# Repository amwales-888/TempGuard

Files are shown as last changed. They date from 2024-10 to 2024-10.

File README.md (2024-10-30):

# TempGuard
PID Temperature Controller dsPIC33EV64GM004 Hardware/Firmware 

Initial requirements were to control the temperature of an enclosed system, holding it as close as possible to a set temperature during operation. Venting air out of the enclosure using a FAN would quickly bring the temperature inside the enclosure to match the outside temperature which was unacceptable. Using an MCU we can monitor the temperature and vent air using a fan at a controlled rate. PID algorythms are commonly used in such systems - ['A proportional–integral–derivative controller (PID controller or three-term controller) is a control loop mechanism employing feedback that is widely used in industrial control systems and a variety of other applications requiring continuously modulated control.'](https://en.wikipedia.org/wiki/Proportional%E2%80%93integral%E2%80%93derivative_controller)

[dsPIC33EV64GM004](https://www.microchip.com/en-us/product/dsPIC33EV64GM004) MCU using 20MHz oscllator, configured with 140MHz FOSC ( 70 MIPS ). This device was selected based on pincount, cost and flexibility of its peripherals. It is presented in a surface mount 44pin quad flat pack that is easily hand solderable, along with a respectable 64k of flash and 8k RAM.

- 4 Input Capture devices for interfacing with temp sensors supporting [DHT11](docs/DHT11-Technical-Data-Sheet-Translated-Version-1143054.pdf) and [DHT22](docs/DHT22.pdf) protocols
- 3 2-Channel PWM devices running at 25KHz for controlling [4pin PWN fans](docs/4_Wire_PWM_Spec.pdf). Support for 3pin and 2pin fans using PWM on power pin if required
- 1 UART for communication, loggin with a host, configured at 9600 8N1
- 11 GPIOs connected to [2004 LCD (HD44780)](docs/HD44780.pdf) driven using 8bit Data, RS, RW and Enable, reading busy-flag to ensure maximum output throughput
- 12 GPIOs
  - 2 dedicated to rotary encoder ( GPIO4, GPIO5 )
  - 1 dedicated to a button ( GPIO3 )
  - 3 Inputs used to read TACH from 4PIN and 3PIN fans to calculate RPM 
  - 3 Output to FETs used as low-side switches controlling the FAN 12V power in the case of 3pin and 2pin fans and for power off control of 4pin fans
- 3 spare GPIO0, GPIO1, GPIO2 which can be used for notification of ALARM conditions, ie. FAN not spinning or Sensor not returning data.
- 3 Timers
  - TMR1 used as system timer used to monitor 10ms tick for scheduling
  - TMR3 used by PWM hardware
  - TMR4 used as high frequency timer with 7.3us tick

The system runs with a simple co-operative multitasking round-robin scheduler with a 10ms tick rate and ability to use a second high resultion timer with a 7us period. Tasks can be scheduled with or without a period, added and removed during operation. All tasks are non-blocking.

User interaction is through an LCD display current value from the attached temp sensors and fans. A rotary encoder and button can be used to navigate menus and change settings.

The LCD is updated from an in memory buffer at >120 times a second.

Ouput is also sent via UART over USB for logging purposes.

The firmware was developed usng the Microchip tools, [MPLABX](https://www.microchip.com/en-us/tools-resources/develop/mplab-x-ide) (v6.10) using [XC16](https://www.microchip.com/en-us/tools-resources/develop/mplab-xc-compilers/xc16) (v2.10) compiler and [MCC](https://www.microchip.com/en-us/tools-resources/configure/mplab-code-configurator) (v5) used to generate system, clock and initialisation code for hardware peripherals.

The firmware is written to the MCU in-circuit using a Microchip [Pickit5](https://www.microchip.com/en-us/development-tool/PG164150). Using the Pickit5 it is also possible to do source level debugging of the MCU while in-circuit.

For test and verification the first version of the device was coded on a dsPIC33EV64GM002 28pin DIP version of the device and soldered onto stripboard, the results for a 40minute session were logged, once the enclosure reached the required set temperature their was little to no deviation seen over the 40minutes.

## Hardware/Enclosure

<table>
  <tr>
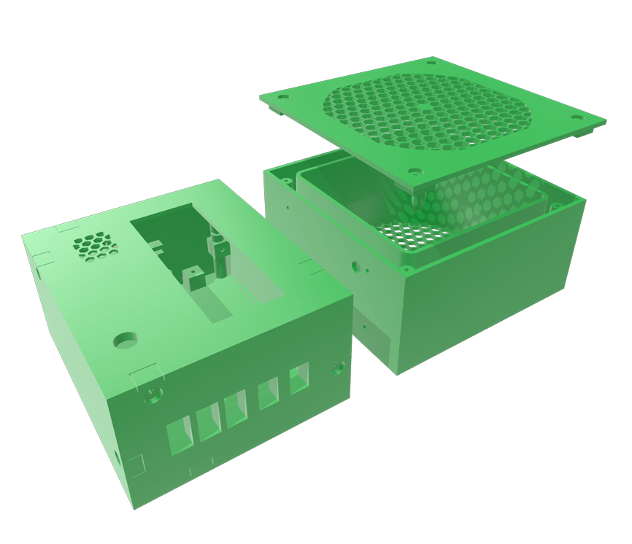
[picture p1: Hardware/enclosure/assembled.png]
    <td colspan="2"> </td>
  </tr>
  <tr>
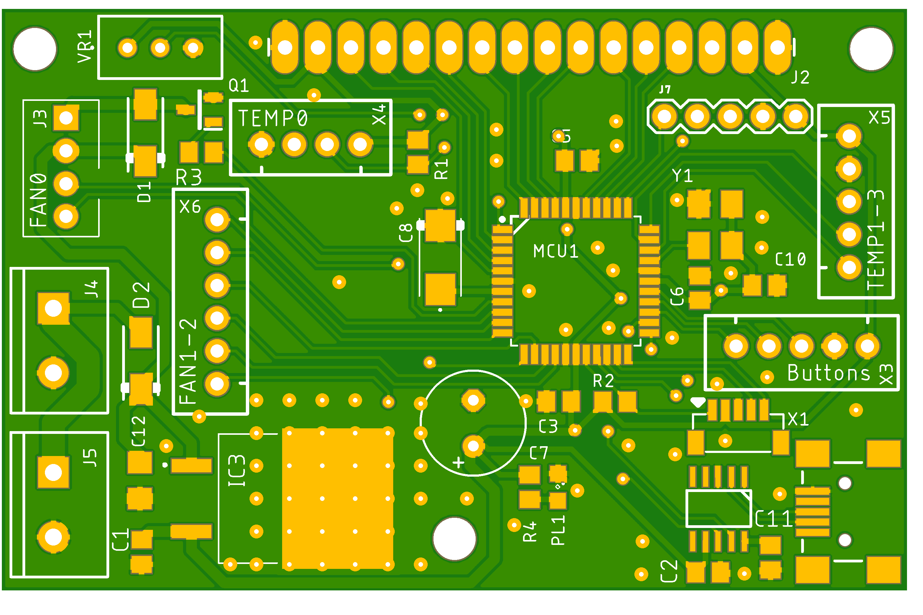
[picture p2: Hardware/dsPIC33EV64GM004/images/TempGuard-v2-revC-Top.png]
    <td> </td>
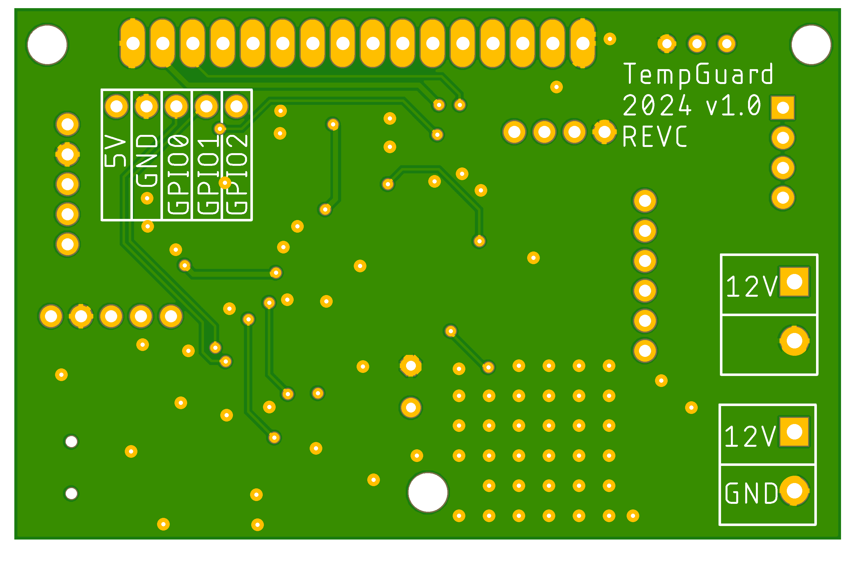
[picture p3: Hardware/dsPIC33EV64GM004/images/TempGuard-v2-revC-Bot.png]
    <td> </td>
  </tr>
  <tr>
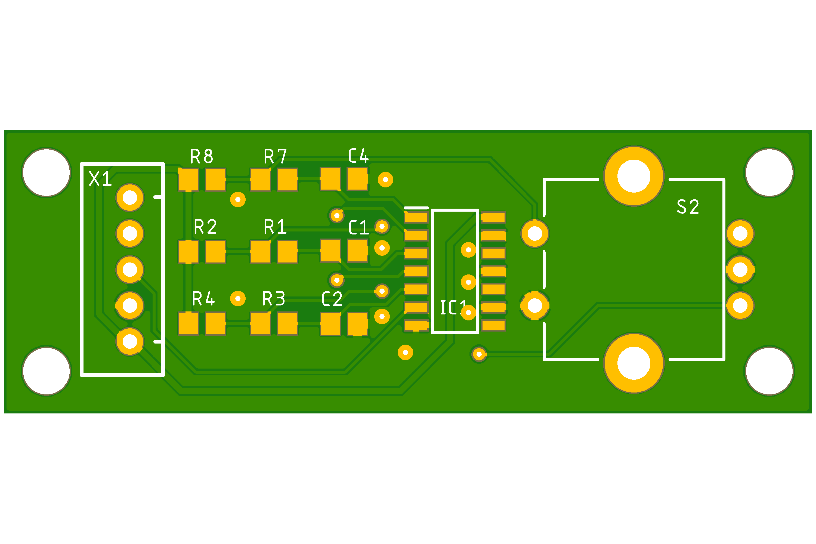
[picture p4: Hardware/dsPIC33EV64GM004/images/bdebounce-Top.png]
    <td> </td>
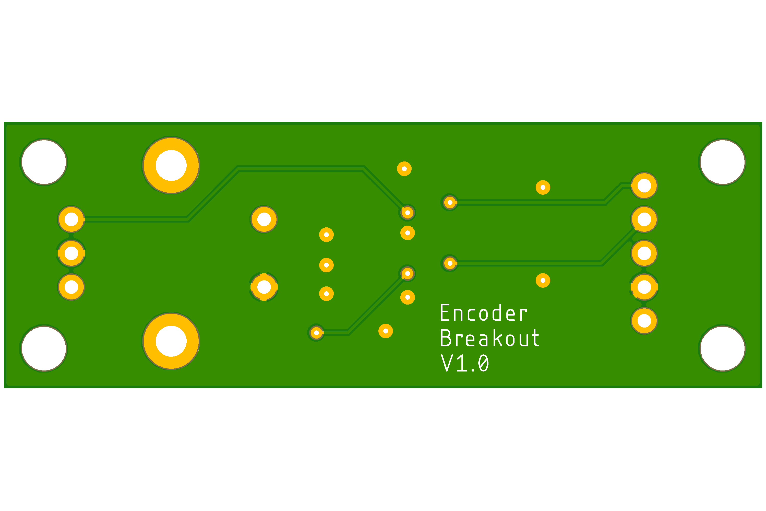
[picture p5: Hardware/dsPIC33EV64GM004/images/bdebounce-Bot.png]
    <td> </td>
  </tr>
  <tr>
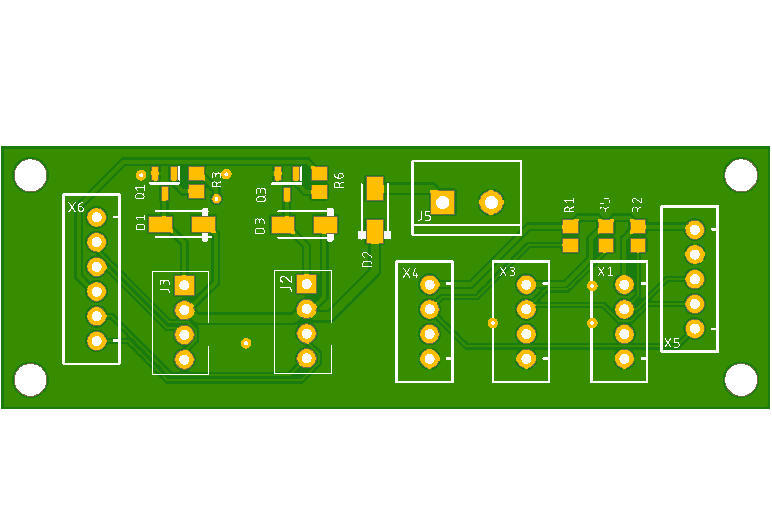
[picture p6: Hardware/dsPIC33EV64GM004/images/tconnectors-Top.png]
    <td> </td>
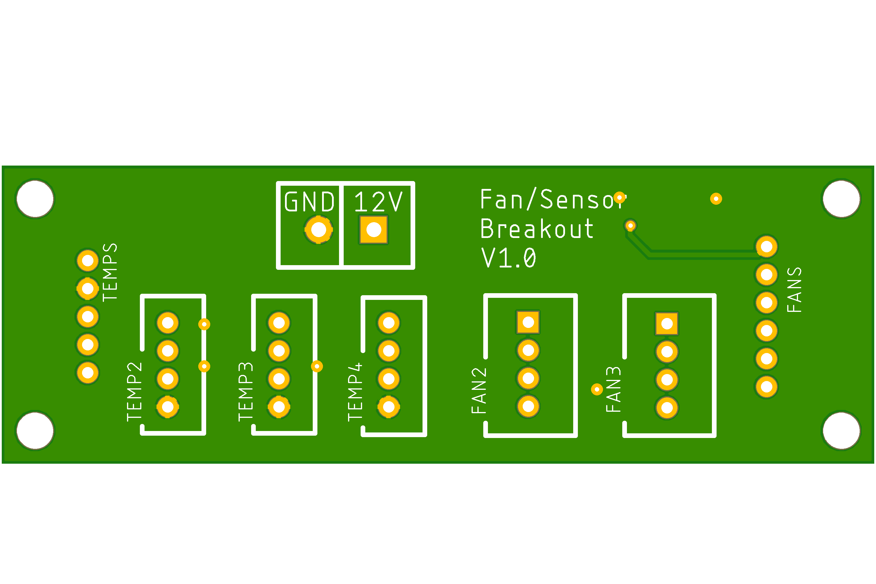
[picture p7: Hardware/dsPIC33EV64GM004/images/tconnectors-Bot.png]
    <td> </td>
  </tr>
</table>

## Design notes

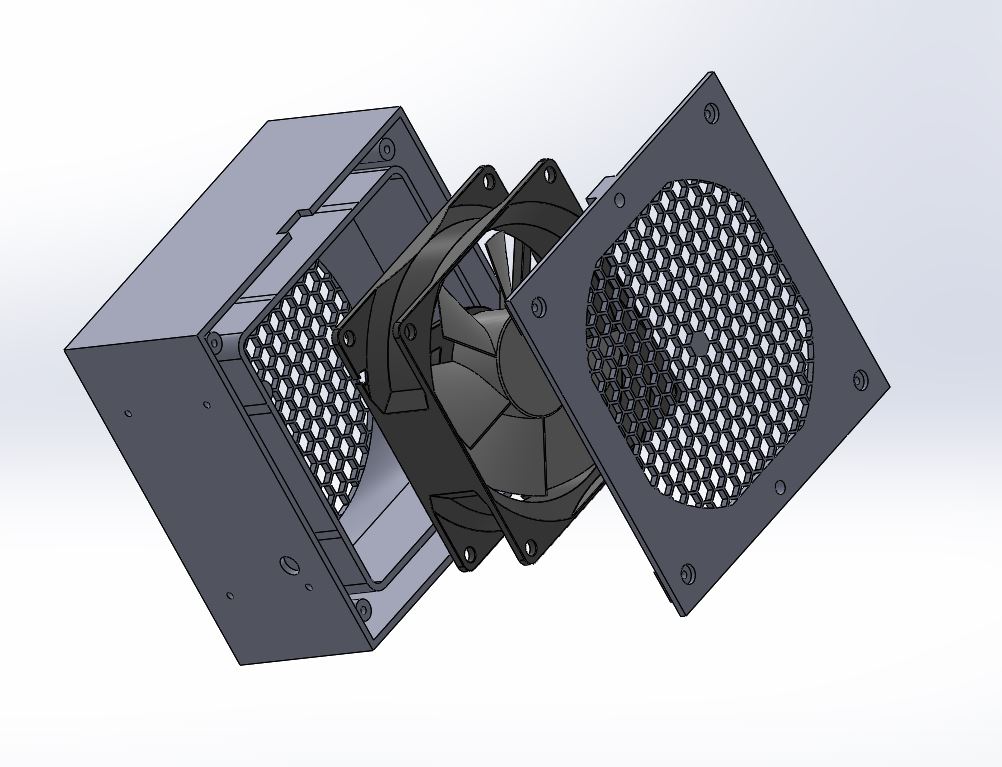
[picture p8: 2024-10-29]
Hardware/enclosure/fan.jpg

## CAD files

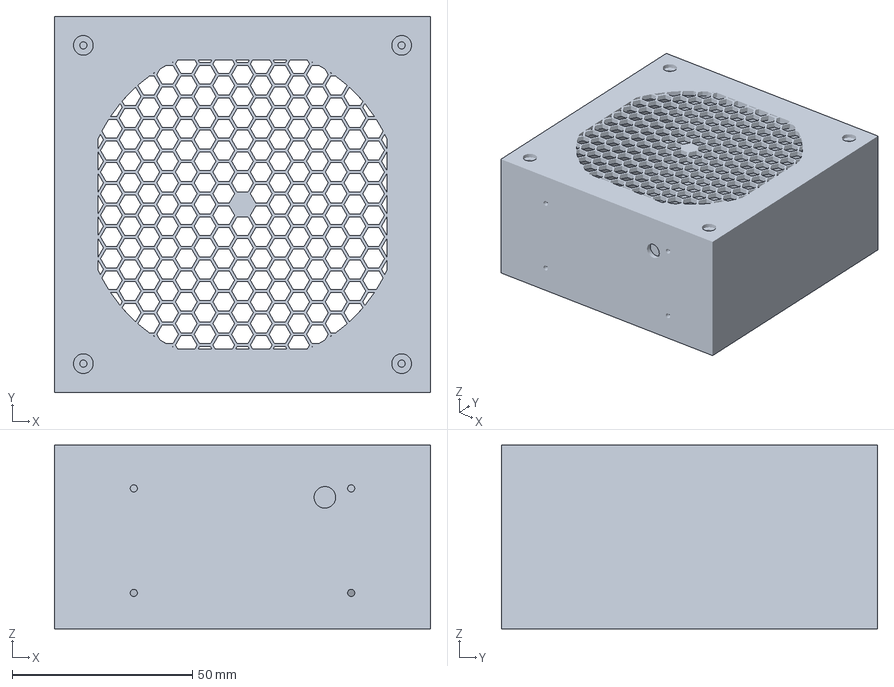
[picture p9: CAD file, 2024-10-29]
Hardware/enclosure/fanenclosure-v2.3MF
104.3 x 104.3 x 51.0 mm

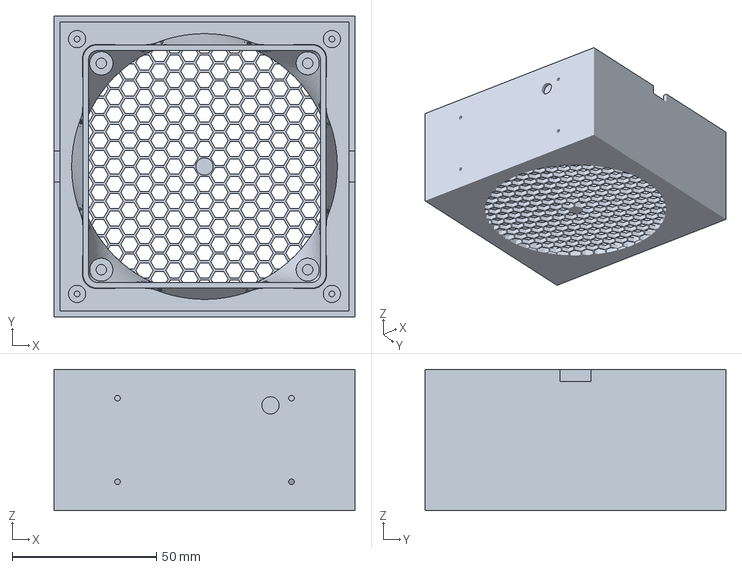
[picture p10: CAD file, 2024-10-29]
Hardware/enclosure/Fan1.3MF
104.3 x 104.3 x 49.0 mm

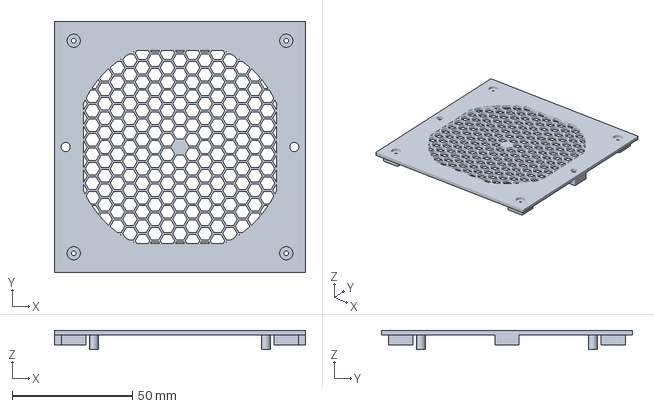
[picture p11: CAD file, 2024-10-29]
Hardware/enclosure/Fan2.3MF
104.3 x 104.3 x 8.00 mm

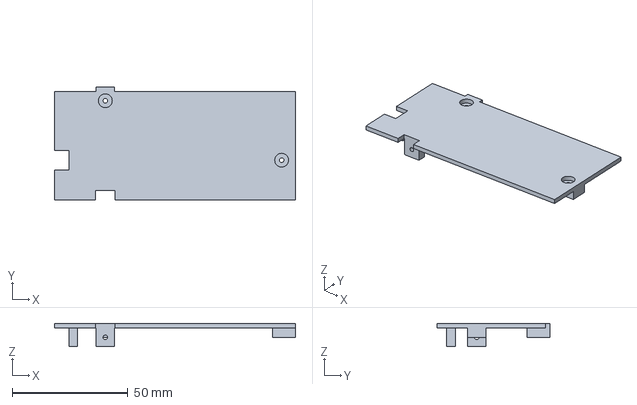
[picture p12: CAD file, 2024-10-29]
Hardware/enclosure/Part5.3MF
104.3 x 49.0 x 10.0 mm

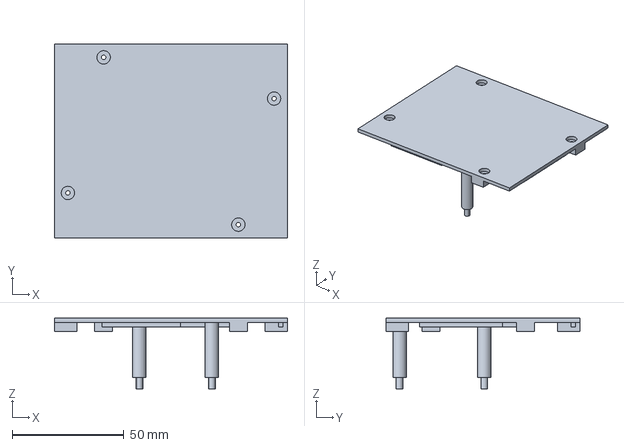
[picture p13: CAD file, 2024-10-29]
Hardware/enclosure/Part6.3MF
104.3 x 86.9 x 31.7 mm

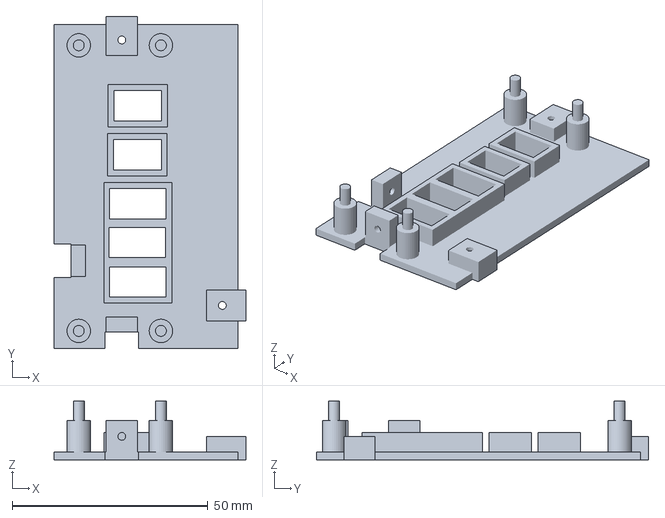
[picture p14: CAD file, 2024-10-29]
Hardware/enclosure/Part1.3MF
49.0 x 84.9 x 15.0 mm

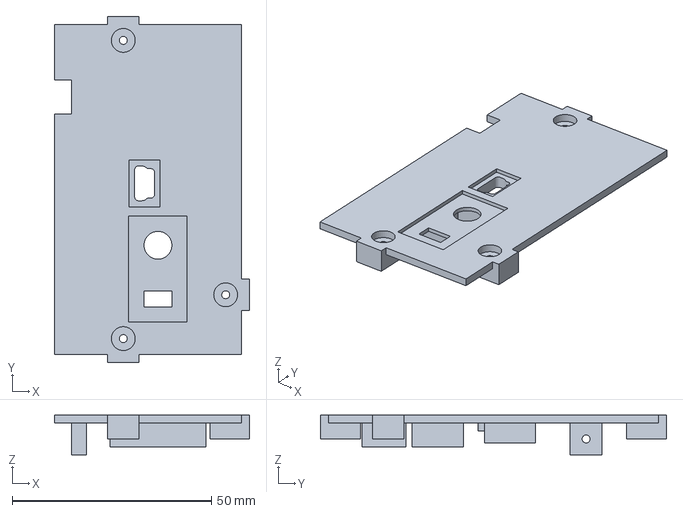
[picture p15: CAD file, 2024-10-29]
Hardware/enclosure/Part4.3MF
49.0 x 86.9 x 10.0 mm

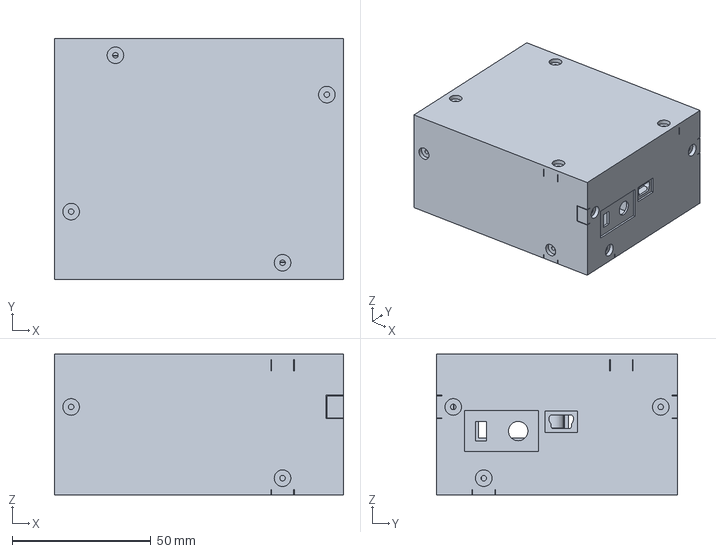
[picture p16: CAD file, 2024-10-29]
Hardware/enclosure/tempguard-v2.3MF
104.3 x 86.9 x 50.8 mm

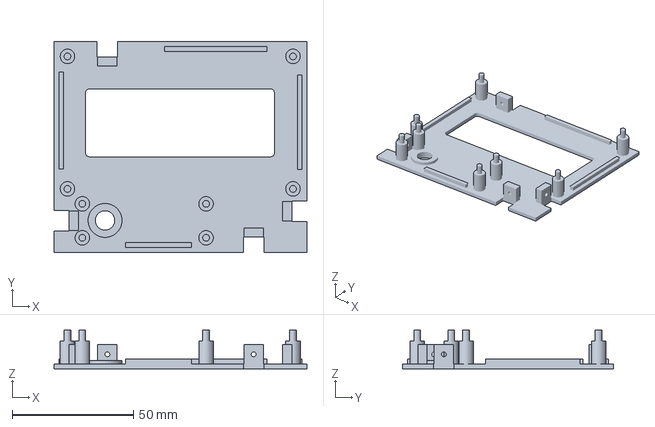
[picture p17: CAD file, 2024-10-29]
Hardware/enclosure/Part2.3MF
104.3 x 86.9 x 16.0 mm

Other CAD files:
Hardware/enclosure/Part3.3MF

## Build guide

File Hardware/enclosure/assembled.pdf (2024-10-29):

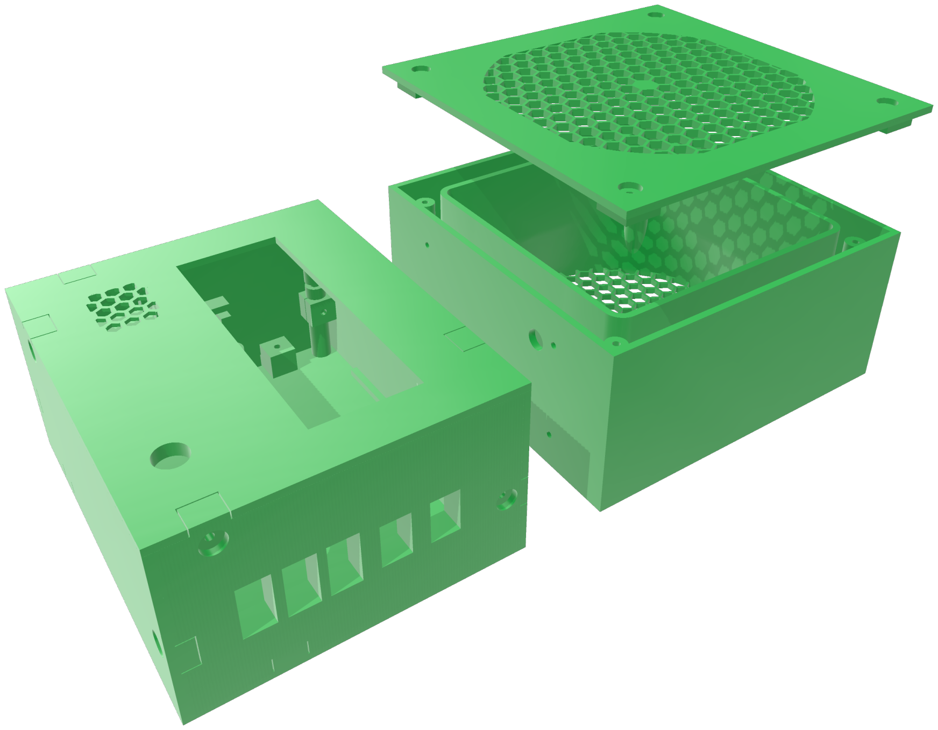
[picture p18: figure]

fanenclosure-v2

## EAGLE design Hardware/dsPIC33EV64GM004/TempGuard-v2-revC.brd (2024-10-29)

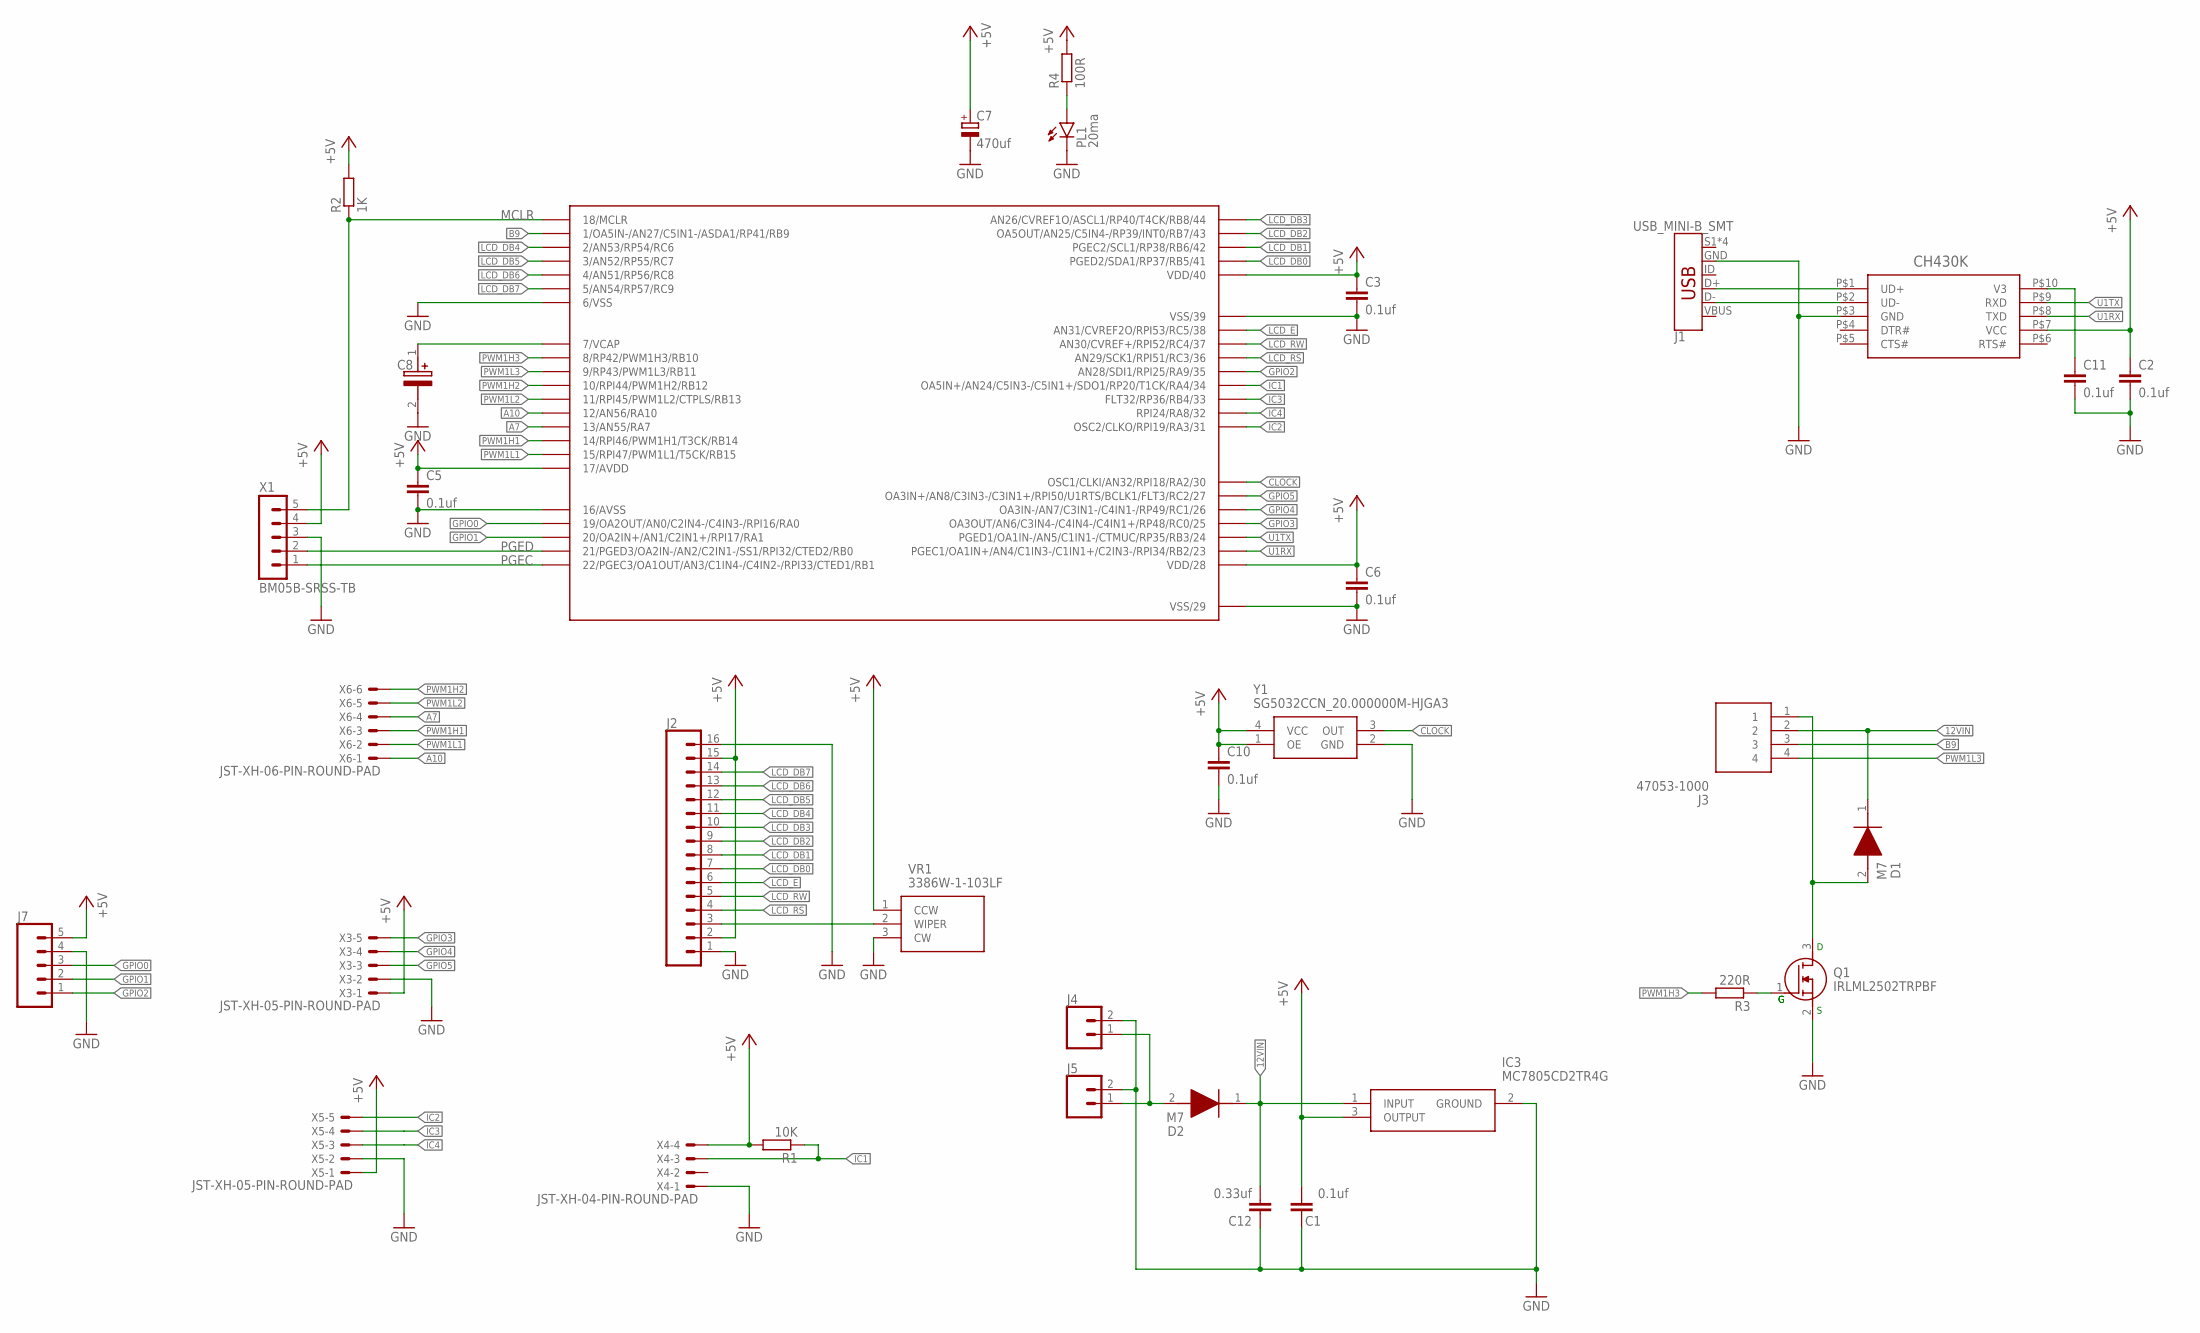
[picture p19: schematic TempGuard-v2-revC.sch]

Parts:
C1, C2, C3, C5, C6, C10, C11: 0.1uf; C0805
C7: 470uf; E3,5-8
C8: T491C106K016ATAUTO; T491C
C12: 0.33uf; C1206
D1, D2: M7; DIOM5327X240N
IC3: MC7805CD2TR4G
J1: USB_MINI-B_SMT; USB-MINIB
J2: CONN_16LONGPADS; 1X16_LONGPADS
J3: 47053-1000; 470531000
J4, J5: CONN_025MM; SCREWTERMINAL-5MM-2
J7: CONN_05; 1X05
MCU1: DSPIC33EV64GM004-I/PT; QFP80P1200X1200X120-44
PL1: 20ma; SML0805
Q1: IRLML2502TRPBF; SOT95P237X112-3N
R1: 10K; R0805
R2: 1K; R0805
R3: 220R; R0805
R4: 100R; R0805
U$1: CH430K; ESSOP-10
VR1: 3386W-1-103LF; 3386W
X1: BM05B-SRSS-TB
X3, X5: JST-XH-05-PIN-ROUND-PAD; JST-XH-05-PACKAGE-ROUND-PAD
X4: JST-XH-04-PIN-ROUND-PAD; JST-XH-04-PACKAGE-ROUND-PAD
X6: JST-XH-06-PIN-ROUND-PAD; JST-XH-06-PACKAGE-ROUND-PAD
Y1: SG5032CCN_20.000000M-HJGA3; SG5032CCN20000000MHJGA3

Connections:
12VIN: C12.2, D1.1 (K), D2.1 (K), IC3.1 (INPUT), J3.2
+5V: C1.2, C2.1, C3.1, C5.1, C6.1, C7.+, C10.1, IC3.3 (OUTPUT), J2.2, J2.15, J7.5, MCU1.17 (17/AVDD), MCU1.28 (VDD/28), MCU1.40 (VDD/40), R1.2, R2.2, R4.2, U$1.P$7 (VCC), VR1.1 (CCW), X1.4, X3.1, X4.4, X5.1, Y1.1 (OE), Y1.4 (VCC)
A7: MCU1.13 (13/AN55/RA7), X6.4
A10: MCU1.12 (12/AN56/RA10), X6.1
B9: J3.3, MCU1.1 (1/OA5IN-/AN27/C5IN1-/ASDA1/RP41/RB9)
CLOCK: MCU1.30 (OSC1/CLKI/AN32/RPI18/RA2/30), Y1.3 (OUT)
GND: C1.1, C2.2, C3.2, C5.2, C6.2, C7.-, C8.2 (-), C10.2, C11.2, C12.1, IC3.2 (GROUND), J1.GND, J2.1, J2.16, J4.2, J5.2, J7.4, MCU1.6 (6/VSS), MCU1.16 (16/AVSS), MCU1.29 (VSS/29), MCU1.39 (VSS/39), PL1.C, Q1.2 (S), U$1.P$3 (GND), VR1.3 (CW), X1.3, X3.2, X4.1, X5.2, Y1.2 (GND)
GPIO0: J7.3, MCU1.19 (19/OA2OUT/AN0/C2IN4-/C4IN3-/RPI16/RA0)
GPIO1: J7.2, MCU1.20 (20/OA2IN+/AN1/C2IN1+/RPI17/RA1)
GPIO2: J7.1, MCU1.35 (AN28/SDI1/RPI25/RA9/35)
GPIO3: MCU1.25 (OA3OUT/AN6/C3IN4-/C4IN4-/C4IN1+/RP48/RC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), X3.5
GPIO4: MCU1.26 (OA3IN-/AN7/C3IN1-/C4IN1-/RP49/RC1/26), X3.4
GPIO5: MCU1.27 (OA3IN+/AN8/C3IN3-/C3IN1+/RPI50/U1RTS/BC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), X3.3
IC1: MCU1.34 (OA5IN+/AN24/C5IN3-/C5IN1+/SDO1/RP20/T1C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), R1.1, X4.3
IC2: MCU1.31 (OSC2/CLKO/RPI19/RA3/31), X5.5
IC3: MCU1.33 (FLT32/RP36/RB4/33), X5.4
IC4: MCU1.32 (RPI24/RA8/32), X5.3
LCD_DB0: J2.7, MCU1.41 (PGED2/SDA1/RP37/RB5/41)
LCD_DB1: J2.8, MCU1.42 (PGEC2/SCL1/RP38/RB6/42)
LCD_DB2: J2.9, MCU1.43 (OA5OUT/AN25/C5IN4-/RP39/INT0/RB7/43)
LCD_DB3: J2.10, MCU1.44 (AN26/CVREF1O/ASCL1/RP40/T4CK/RB8/44)
LCD_DB4: J2.11, MCU1.2 (2/AN53/RP54/RC6)
LCD_DB5: J2.12, MCU1.3 (3/AN52/RP55/RC7)
LCD_DB6: J2.13, MCU1.4 (4/AN51/RP56/RC8)
LCD_DB7: J2.14, MCU1.5 (5/AN54/RP57/RC9)
LCD_E: J2.6, MCU1.38 (AN31/CVREF2O/RPI53/RC5/38)
LCD_RS: J2.4, MCU1.36 (AN29/SCK1/RPI51/RC3/36)
LCD_RW: J2.5, MCU1.37 (AN30/CVREF+/RPI52/RC4/37)
MCLR: MCU1.18 (18/MCLR), R2.1, X1.5
unnamed: D1.2 (A), J3.1, Q1.3 (D)
unnamed: J2.3, VR1.2 (WIPER)
unnamed: PL1.A, R4.1
unnamed: Q1.1 (G), R3.1
unnamed: D2.2 (A), J4.1, J5.1
unnamed: C11.1, U$1.P$10 (V3)
PGEC: MCU1.22 (22/PGEC3/OA1OUT/AN3/C1IN4-/C4IN2-/RPI33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), X1.1
PGED: MCU1.21 (21/PGED3/OA2IN-/AN2/C2IN1-/SS1/RPI32/CT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), X1.2
PWM1H1: MCU1.14 (14/RPI46/PWM1H1/T3CK/RB14), X6.3
PWM1H2: MCU1.10 (10/RPI44/PWM1H2/RB12), X6.6
PWM1H3: MCU1.8 (8/RP42/PWM1H3/RB10), R3.2
PWM1L1: MCU1.15 (15/RPI47/PWM1L1/T5CK/RB15), X6.2
PWM1L2: MCU1.11 (11/RPI45/PWM1L2/CTPLS/RB13), X6.5
PWM1L3: J3.4, MCU1.9 (9/RP43/PWM1L3/RB11)
U1RX: MCU1.23 (PGEC1/OA1IN+/AN4/C1IN3-/C1IN1+/C2IN3-/R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), U$1.P$8 (TXD)
U1TX: MCU1.24 (PGED1/OA1IN-/AN5/C1IN1-/CTMUC/RP35/RB3/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), U$1.P$9 (RXD)
USB_N: J1.D-, U$1.P$2 (UD-)
USB_P: J1.D+, U$1.P$1 (UD+)
VBUS: J1.VBUS
VCAP: C8.1 (+), MCU1.7 (7/VCAP)

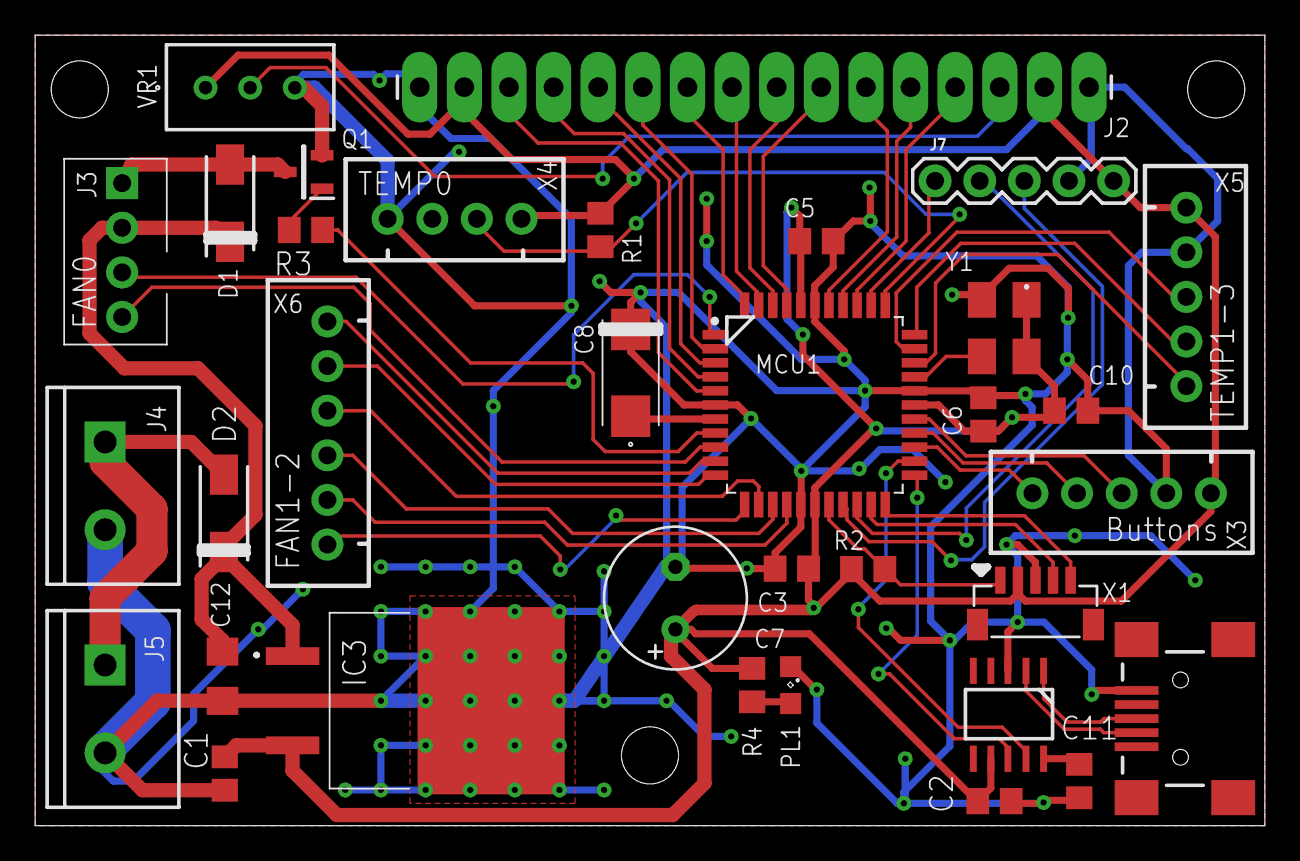
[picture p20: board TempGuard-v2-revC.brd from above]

Board: 2 copper layers, 70.0 x 45.0 mm, 34 parts (0 on the bottom side), 48 nets.

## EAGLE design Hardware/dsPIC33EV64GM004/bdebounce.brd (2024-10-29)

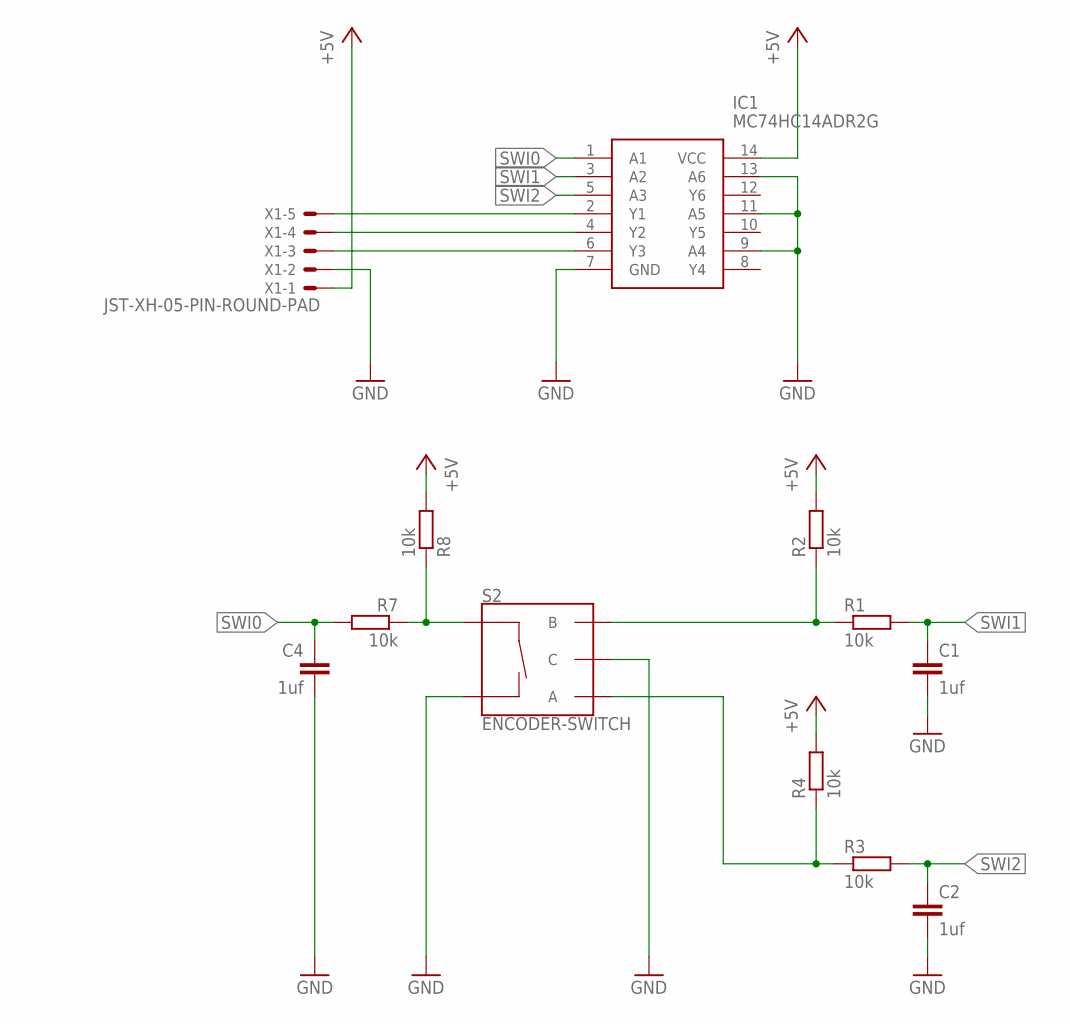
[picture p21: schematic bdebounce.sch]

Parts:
C1, C2, C4: 1uf; C0805
IC1: MC74HC14ADR2G; SOIC127P600X175-14N
R1, R2, R3, R4, R7, R8: 10k; R0805
S2: ENCODER-SWITCH; ROTARY_ENC_PLAIN
X1: JST-XH-05-PIN-ROUND-PAD; JST-XH-05-PACKAGE-ROUND-PAD

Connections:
+5V: IC1.14 (VCC), R2.2, R4.2, R8.2, X1.1
GND: C1.2, C2.2, C4.2, IC1.7 (GND), IC1.9 (A4), IC1.11 (A5), IC1.13 (A6), S2.C, S2.SW-, X1.2
unnamed: IC1.6 (Y3), X1.3
SW0: R7.1, R8.1, S2.SW+
SW1: R1.1, R2.1, S2.B
SW2: R3.1, R4.1, S2.A
SWI0: C4.1, IC1.1 (A1), R7.2
SWI1: C1.1, IC1.3 (A2), R1.2
SWI2: C2.1, IC1.5 (A3), R3.2
SWO0: IC1.2 (Y1), X1.5
SWO1: IC1.4 (Y2), X1.4

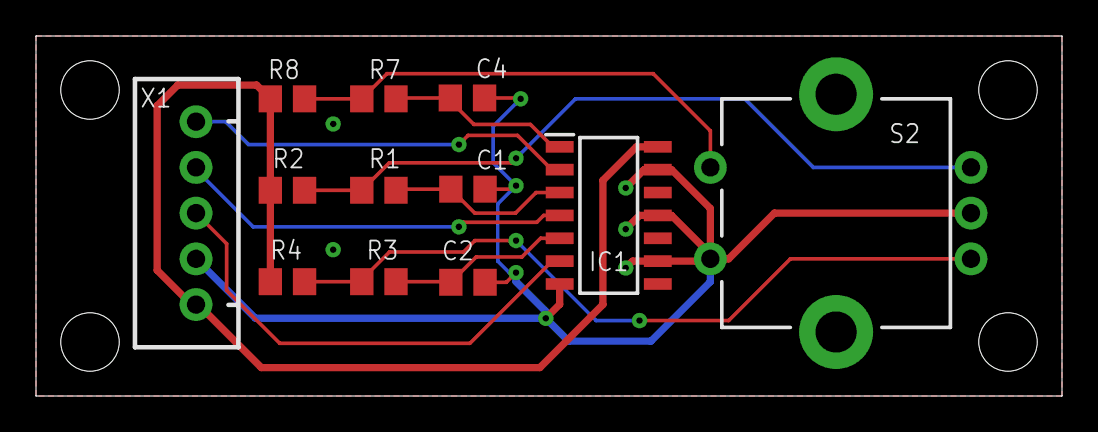
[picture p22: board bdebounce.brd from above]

Board: 2 copper layers, 57.0 x 20.0 mm, 12 parts (0 on the bottom side), 11 nets.

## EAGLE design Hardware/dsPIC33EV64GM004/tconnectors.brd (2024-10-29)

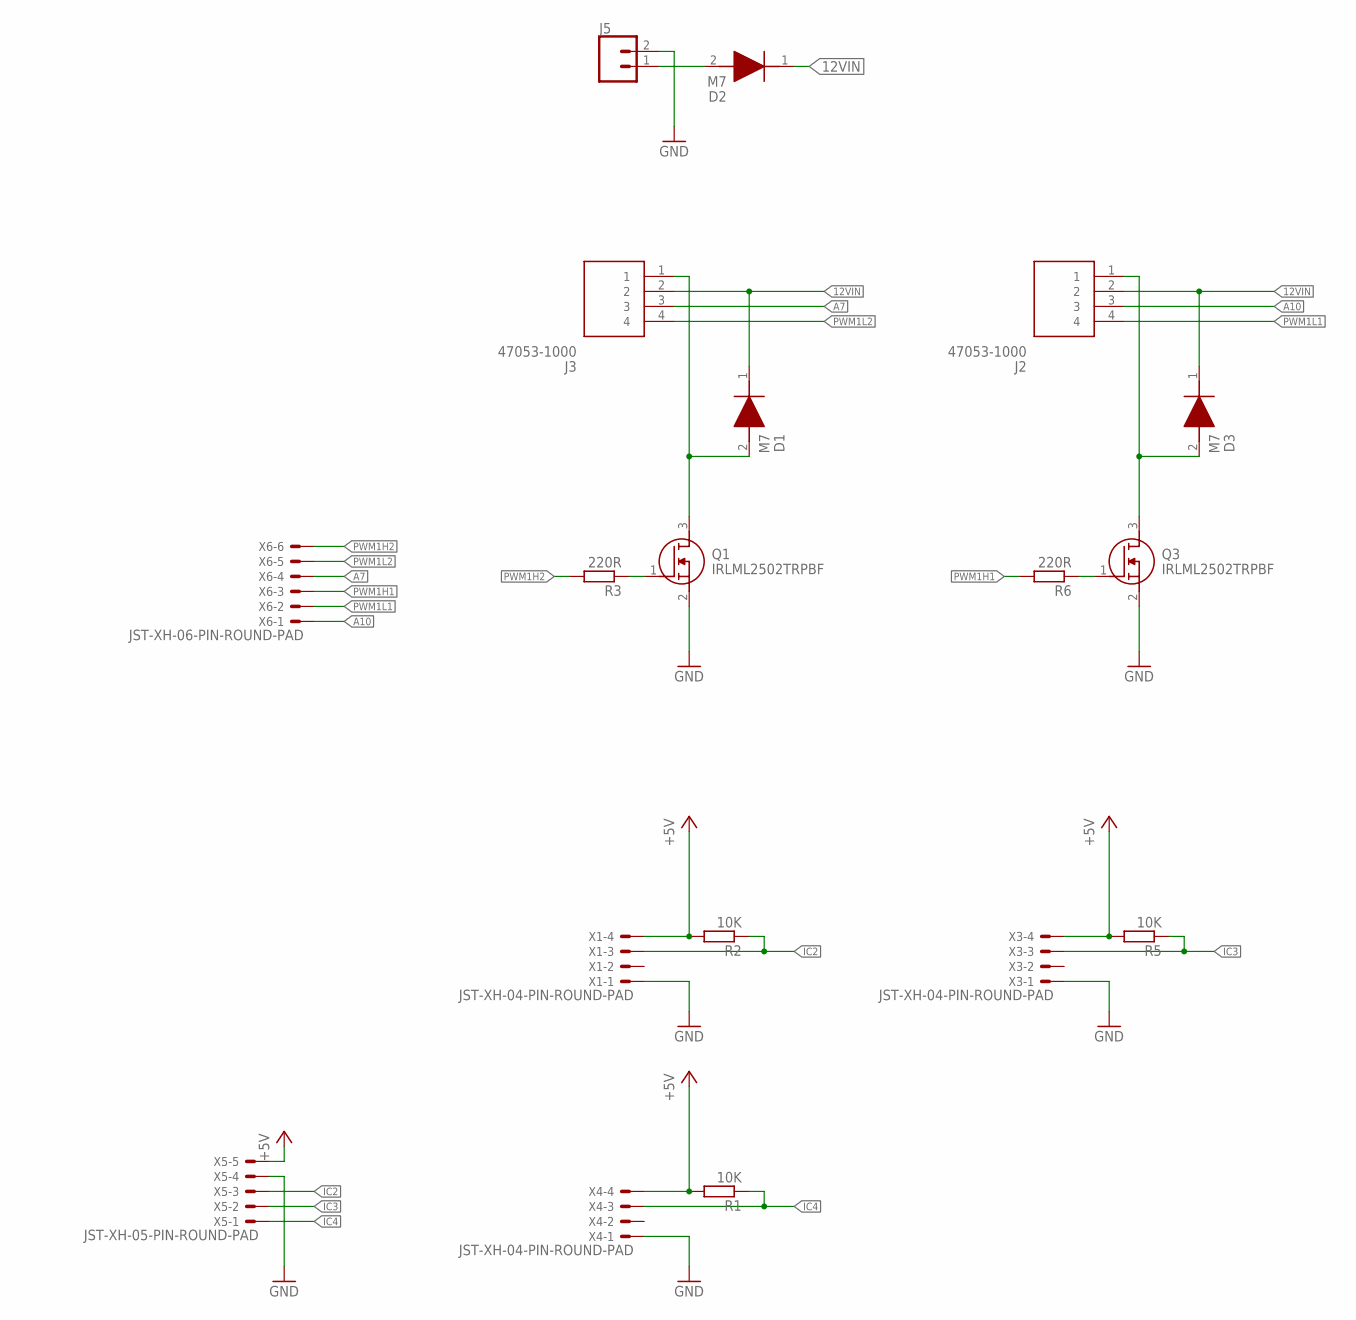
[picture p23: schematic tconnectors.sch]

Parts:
D1, D2, D3: M7; DIOM5327X240N
J2, J3: 47053-1000; 470531000
J5: CONN_025MM; SCREWTERMINAL-5MM-2
Q1, Q3: IRLML2502TRPBF; SOT95P237X112-3N
R1, R2, R5: 10K; R0805
R3, R6: 220R; R0805
X1, X3, X4: JST-XH-04-PIN-ROUND-PAD; JST-XH-04-PACKAGE-ROUND-PAD
X5: JST-XH-05-PIN-ROUND-PAD; JST-XH-05-PACKAGE-ROUND-PAD
X6: JST-XH-06-PIN-ROUND-PAD; JST-XH-06-PACKAGE-ROUND-PAD

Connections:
12VIN: D1.1 (K), D2.1 (K), D3.1 (K), J2.2, J3.2
+5V: R1.2, R2.2, R5.2, X1.4, X3.4, X4.4, X5.5
A7: J3.3, X6.4
A10: J2.3, X6.1
GND: J5.2, Q1.2 (S), Q3.2 (S), X1.1, X3.1, X4.1, X5.4
IC2: R2.1, X1.3, X5.3
IC3: R5.1, X3.3, X5.2
IC4: R1.1, X4.3, X5.1
unnamed: D1.2 (A), J3.1, Q1.3 (D)
unnamed: D3.2 (A), J2.1, Q3.3 (D)
unnamed: Q3.1 (G), R6.1
unnamed: Q1.1 (G), R3.1
unnamed: D2.2 (A), J5.1
PWM1H1: R6.2, X6.3
PWM1H2: R3.2, X6.6
PWM1L1: J2.4, X6.2
PWM1L2: J3.4, X6.5

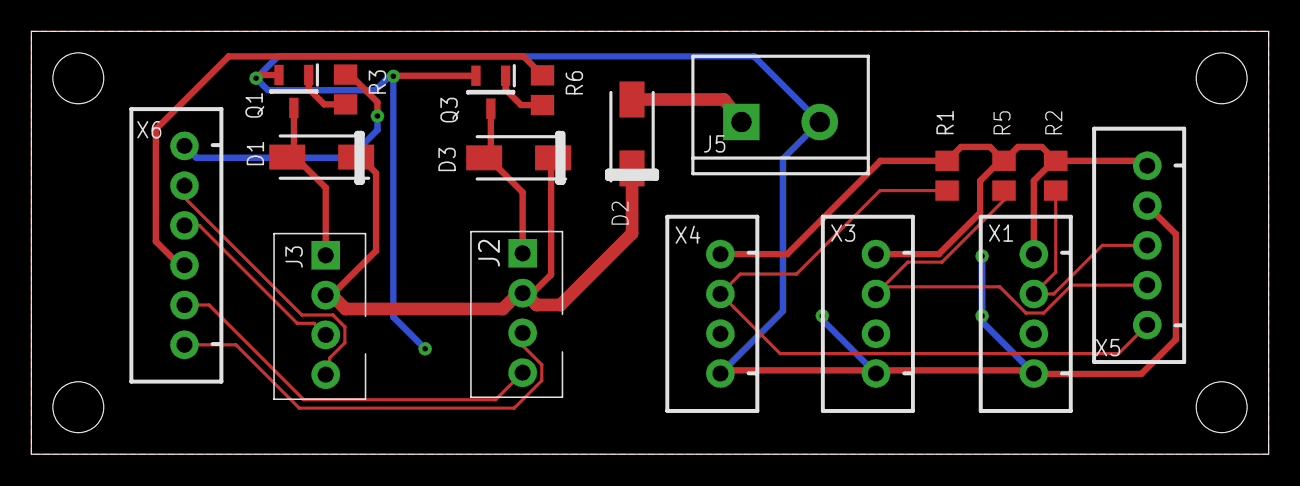
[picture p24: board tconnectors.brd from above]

Board: 2 copper layers, 79.0 x 27.0 mm, 18 parts (0 on the bottom side), 17 nets.

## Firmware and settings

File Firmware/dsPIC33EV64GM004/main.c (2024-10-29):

/**
  Generated main.c file from MPLAB Code Configurator

  @Company
    Microchip Technology Inc.

  @File Name
    main.c

  @Summary
    This is the generated main.c using PIC24 / dsPIC33 / PIC32MM MCUs.

  @Description
    This source file provides main entry point for system initialization and application code development.
    Generation Information :
        Product Revision  :  PIC24 / dsPIC33 / PIC32MM MCUs - 1.171.4
        Device            :  dsPIC33EV64GM004
    The generated drivers are tested against the following:
        Compiler          :  XC16 v2.10
        MPLAB 	          :  MPLAB X v6.05
*/

/*
    (c) 2020 Microchip Technology Inc. and its subsidiaries. You may use this
    software and any derivatives exclusively with Microchip products.

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
    IN NO EVENT WILL MICROCHIP BE LIABLE FOR ANY INDIRECT, SPECIAL, PUNITIVE,
    INCIDENTAL OR CONSEQUENTIAL LOSS, DAMAGE, COST OR EXPENSE OF ANY KIND
    WHATSOEVER RELATED TO THE SOFTWARE, HOWEVER CAUSED, EVEN IF MICROCHIP HAS
    BEEN ADVISED OF THE POSSIBILITY OR THE DAMAGES ARE FORESEEABLE. TO THE
    FULLEST EXTENT ALLOWED BY LAW, MICROCHIP'S TOTAL LIABILITY ON ALL CLAIMS IN
    ANY WAY RELATED TO THIS SOFTWARE WILL NOT EXCEED THE AMOUNT OF FEES, IF ANY,
    THAT YOU HAVE PAID DIRECTLY TO MICROCHIP FOR THIS SOFTWARE.

    MICROCHIP PROVIDES THIS SOFTWARE CONDITIONALLY UPON YOUR ACCEPTANCE OF THESE
    TERMS.
*/

/**
  Section: Included Files
*/

#include <xc.h>
#include <time.h>
#include <stdio.h>
#include <stdint.h>
#include <string.h>

#include "mcc_generated_files/system.h"
#include "mcc_generated_files/tmr1.h"
#include "mcc_generated_files/pin_manager.h"
#include "mcc_generated_files/uart1.h"
#include "mcc_generated_files/tmr4.h"
#include "mcc_generated_files/ic1.h"
#include "mcc_generated_files/ic2.h"
#include "mcc_generated_files/ic3.h"
#include "mcc_generated_files/ic4.h"
#include "mcc_generated_files/pwm.h"

#include "scheduler.h"
#include "pid.h"
#include "button.h"
#include "encoder.h"
#include "lcd.h"
#include "dht.h"
#include "videoBuffer.h"
#include "tach.h"
#include "menu.h"
#include "config.h"
#include "format.h"

static struct config_s cfg;
static uint8_t videoBuffer[LCDROWS * LCDCOLS];

#define TMR4TICKTOUS      1.8
#define TMR4MSTOTICK(ms) ((ms)/(0.001*(TMR4TICKTOUS)))
#define TMR4USTOTICK(us) ((us)/TMR4TICKTOUS)

#define TEMPID0 0
#define TEMPID1 1
#define TEMPID2 2
#define TEMPID3 3

#define ENCODERID 0 

#define ENCODERGPIOA  4 /* GPIO3 */
#define ENCODERGPIOB  5 /* GPIO4 */
#define BUTTONGPIOID  3 /* GPIO5 */

#define PWMPERIOD1 5600 /* PHASE1 25KHz */
#define PWMPERIOD2 5600 /* PHASE2 25KHz */
#define PWMPERIOD3 5600 /* PHASE3 25KHz */

static void setFanOn(uint16_t pwmId);
static void setFanOff(uint16_t pwmId);
static void pwmSetDutyCycle(uint16_t pwmId, uint32_t dutyCyclePercentage);
static void userInterface(void *data);
static void buttonDebounce(void *data);
static void buttonPoll(void *data);
static void buttonCallback(uint8_t id, enum buttonState_e state, void *data);
static void encoderPoll(void *data);
static void lcdUpdateVideo(void *data);
static void readTemperatureDelay(void *data);
static void readTemperature(void *data);
static void ICInit(void *data);
static void ICStop(void *data);
static uint16_t ICCaptureDataRead(void *data);
static void ICSetDigitalOuputLow(void *data);
static void ICSetDigitalInput(void *data);
static void monitorTemp(uint16_t tempId);
static void monitorAllTemps(void *data);
static void updateLCDInit(void *data);
static void tachRead(void *data);
static void updateLCDUpload(void *data);
#ifdef BLINK7BIT
static void videoBlink(void *data);
#endif
static void logData(void *data);
static void monitorAlarm(void *data);


static struct config_s cfg;
static uint8_t videoBuffer[LCDROWS * LCDCOLS];

const uint8_t charTable[] = {

  0b10000, /* Right Arrow */
  0b11000,
  0b11100,
  0b11110,
  0b11100,
  0b11000,
  0b10000,    
  0b00000,

  0b00001, /* Left Arrow */
  0b00011,
  0b00111,
  0b01111,
  0b00111,
  0b00011,
  0b00001,    
  0b00000,

  0b00100, /* Up Arrow */
  0b01110,
  0b11111,
  0b00000,
  0b00000,
  0b00000,
  0b00000,
  0b00000,
  
  0b00000, /* Down Arrow */
  0b00000,
  0b00000,
  0b00000,
  0b11111,
  0b01110,
  0b00100,
  0b00000,
   
  0b00100, /* UpDown Arrow */
  0b01110,
  0b11111,
  0b00000,
  0b11111,
  0b01110,
  0b00100,
  0b00000,

};

static struct uploadChar_s uploadCharData = {

    0,
    0,
    5,
    &charTable[0],    
};

static uint8_t updateLCDCTX;
static uint8_t temperatureDelayCTX;

/* Processes */

static PROCESSALLOCATE(userInterfaceProcess,        250,                          userInterface,        (void *)0 );
static PROCESSALLOCATE(buttonDebounceProcess,       DEBOUNCE_INTEGRATOR_DELAYMS,  buttonDebounce,       (void *)0 );
static PROCESSALLOCATE(buttonPollProcess,           DEBOUNCE_DELAYMS,             buttonPoll,           (void *)0 );
static PROCESSALLOCATE(encoderPollProcess,          10,                           encoderPoll,          (void *)0 );
static PROCESSALLOCATE(updateLCDInitProcess,        0,                            updateLCDInit,        (void *)&updateLCDCTX );
static PROCESSALLOCATE(updateLCDUploadProcess,      0,                            updateLCDUpload,      (void *)&uploadCharData );
static PROCESSALLOCATE(updateVideoProcess,          0,                            lcdUpdateVideo,       (void *)0 );
static PROCESSALLOCATE(readTemperatureDelayProcess, 250,                          readTemperatureDelay, (void *)&temperatureDelayCTX );
static PROCESSALLOCATE(readTemperatureProcess0,     10,                           readTemperature,      (void *)TEMPID0 );
static PROCESSALLOCATE(readTemperatureProcess1,     10,                           readTemperature,      (void *)TEMPID1 );
static PROCESSALLOCATE(readTemperatureProcess2,     10,                           readTemperature,      (void *)TEMPID2 );
static PROCESSALLOCATE(readTemperatureProcess3,     10,                           readTemperature,      (void *)TEMPID3 );
static PROCESSALLOCATE(monitorAllTempsProcess,      250,                          monitorAllTemps,      (void *)0 );
static PROCESSALLOCATE(tachReadProcess,             250,                          tachRead,             (void *)0 );
static PROCESSALLOCATE(logDataProcess,              1000,                         logData,              (void *)0 );
static PROCESSALLOCATE(monitorAlarmProcess,         1000,                         monitorAlarm,         (void *)0 );

#ifdef BLINK7BIT
static PROCESSALLOCATE(videoBlinkProcess,           500,                          videoBlink,           (void *)0 );
#endif

#ifdef BLINK7BIT
static uint16_t videoBlinkCount;

static void
videoBlinkDelay(void *data) {

    struct process_s *process = (struct process_s *)data;
        
    videoBlinkCount = 2;
    schedulerProcessResetPeriod(process);
    videoSetBlink(0);
}


static void 
videoBlink(void *data) {
    
    if (videoBlinkCount == 0) {
        videoToggleBlink();
    } else {
        videoBlinkCount--;
    }
}
#endif

static void
readTemperatureDelay(void *data) {
    
    uint8_t *ctx = (uint8_t *)data;

    /* start each temperature reading with a delayed offset and
     * finally remove ourself from schedule 
     */

    switch (*ctx) {
        case 0: {
            if (cfg.sensor[0].enabled) {
                schedulerProcessAdd(&readTemperatureProcess0);            
            }
            break;
        }
        case 1: {
            if (cfg.sensor[1].enabled) {
                schedulerProcessAdd(&readTemperatureProcess1);            
            }
            break;
        }
        case 2: {
            if (cfg.sensor[2].enabled) {
                schedulerProcessAdd(&readTemperatureProcess2);            
            }
            break;
        }
        case 3: {
            if (cfg.sensor[3].enabled) {
                schedulerProcessAdd(&readTemperatureProcess3);            
            }
            break;
        }
        case 4: {
            schedulerProcessRemove(&readTemperatureDelayProcess);
            break;        
        }
    }
    
    (*ctx)++;   
}

static void 
readTemperature(void *data) {
    
    uint16_t id = (uint16_t)data;
    
    dhtTemperatureProcess(id);
}

static void 
encoderPoll(void *data) {        
    
    encoderUpdate();    
}

static void 
buttonDebounce(void *data) {
    
    buttonUpdateIntegrator();
}

static void 
buttonPoll(void *data) {

    buttonUpdate();
}

static void 
userInterface(void *data) {

    encoderUpdateChanged(); // Check for any encoder updates, this will
                            // trigger any encoder callbacks, no point doing this more
                            // often that it needs to be done
    
    menuDisplay();
}


void 
TMR1_CallBack(void) {

    /* Callback from TMR1 Interrupt */
    
    schedulerIncrementTicks();
}

enum LCDUploadState_e {
    
    LCDUploading=0,
    LCDUploadComplete,    
};

static enum LCDUploadState_e LCDUploadState;

static void
updateLCDUpload(void *data) {
    
    struct uploadChar_s *p = (struct uploadChar_s *)data;
    
    if (p->count == 0) {
        
        LCDUploadState = LCDUploadComplete;
        
        /* Start video refreshing */
        schedulerProcessAdd(&updateVideoProcess);

        // All characters uploaded remove ourself from process list
        schedulerProcessRemove(&updateLCDUploadProcess);
        return;
    }
            
    if (lcdBusy() == 0) {

        switch (uploadChar(p->position, *(p->ptr), &(p->ctx))) {
            case CHARSTARTEDUPLOAD:
                break;

            case CHARUPLOADING:
                p->ptr++;
                break;

            case CHARUPLOADCOMPLETE:
                p->position++;
                p->count--;
                p->ctx = 0;
                break;
        }
    }
}

static void
updateLCDInit(void *data) {
    
    static uint16_t last = 0;
           uint16_t now  = TMR4_Counter16BitGet();

    /* Using high resolution timer 
     * Cannot use the busy flag during init so wait a 
     * minimum of 5ms between processing
     */ 
    if ((uint16_t)(now - last) > TMR4MSTOTICK(5)) {
                
        if (lcdInitProcess((uint8_t *)data) == LCDREADY) {

            // Upload user defined characters
            schedulerProcessAdd(&updateLCDUploadProcess);
            
            // Init completed remove ourselves from list of active processes        
            schedulerProcessRemove(&updateLCDInitProcess);
            return;
        }

        last = now;
    }
}

static void 
lcdUpdateVideo(void *data) {

    videoBufferRefresh();
}

static void 
encoderCallback(uint16_t id, uint16_t value, void *data) {

    if (id == ENCODERID) {
        
        menuEncoderChanged(value);    
    }
}

static void 
buttonCallback(uint8_t id, enum buttonState_e state, void *data) {

    if (id == BUTTONGPIOID) {
        if (state == BUTTONPRESSED) {       

            menuButtonPressed();
        }
    }
}

static void 
LCDRWSet(uint8_t value, void *data) {

    if (value) {
        LCD_RW_SetHigh();
    } else {
        LCD_RW_SetLow();
    }
}

static void 
LCDRSSet(uint8_t value, void *data) {
    
    if (value) {
        LCD_RS_SetHigh();
    } else {
        LCD_RS_SetLow();        
    }
}

static void 
LCDWriteDB(uint8_t byte, void *data) {
    
    // Set DB portbits to output
    
    TRISB &= 0xFE1F; 
    TRISC &= 0xFC3F;
    
    LATB &= (uint16_t)0xFE1F;
    LATB |= (((uint16_t)byte & 0x0F) << 5);
    
    LATC &= (uint16_t)0xFC3F;
    LATC |= (((uint16_t)byte & 0xF0) << 2);      
}

static uint8_t 
LCDReadDB(void *data) {
    
    uint8_t byte = 0;
    
    // Set DB portbits to input
    
    TRISB |= ~0xFE1F; 
    TRISC |= ~0xFC3F; 
   
    byte |= (PORTB & (~0xFE1F)) >> 5; 
    byte |= (PORTC & (~0xFC3F)) >> 2;

    return byte;
}

static void 
LCDESet(uint8_t value, void *data) {
    
    if (value) {
        LCD_E_SetHigh();
    } else {
        LCD_E_SetLow();        
    }
}

static void 
ICInit(void *data) {
    
    uint16_t id = (uint16_t)data;
            
    TMR3 = 0;       // Reset timer used by Input Capture
                    // The timer is shared but the start and duration of
                    // the calls do not overlap so it is safe to reset the
                    // the timer.

    switch (id) {
        case 0: {        
            IC1_Initialize();
            IC1_Start();
            break;
        }
        case 1: {
            IC2_Initialize();
            IC2_Start();
            break;
        }
        case 2: {
            IC3_Initialize();
            IC3_Start();
            break;
        }
        case 3: {
            IC4_Initialize();
            IC4_Start();
            break;
        }
    }
}

static void 
ICStop(void *data) {
   
    uint16_t id = (uint16_t)data;

    switch (id) {
        case 0: {
            IC1_Stop();
            break;
        }
        case 1: {
            IC2_Stop();
            break;
        }
        case 2: {
            IC3_Stop();
            break;
        }
        case 3: {
            IC4_Stop();
            break;
        }
    }
}

static uint16_t
ICCaptureDataRead(void *data) {
    
    uint16_t tempId = (uint16_t)data;

    switch (tempId) {
        case 0: {
            return IC1_CaptureDataRead();
        }
        case 1: {
            return IC2_CaptureDataRead();
        }
        case 2: {
            return IC3_CaptureDataRead();
        }
        case 3: {
            return IC4_CaptureDataRead();
        }
    }
    
    return 0;
}

static void 
ICSetDigitalOuputLow(void *data) {

    uint16_t tempId = (uint16_t)data;

    switch (tempId) {
        case 0: {
            /* IC1 */           
            TRISAbits.TRISA4 = 0; /* Set Digital Output */
            PORTAbits.RA4    = 0; /* Pull Low           */
            break;
        }
        case 1: {
            /* IC2 */
            TRISAbits.TRISA3 = 0; /* Set Digital Output */
            PORTAbits.RA3    = 0; /* Pull Low           */
            break;
        }
        case 2: {            
            /* IC3 */
            TRISBbits.TRISB4 = 0; /* Set Digital Output */
            PORTBbits.RB4    = 0; /* Pull Low           */
            break;
        }
        case 3: {
            /* IC4 */
            TRISAbits.TRISA8 = 0; /* Set Digital Output */
            PORTAbits.RA8    = 0; /* Pull Low           */
            break;
        }
    }    
}

static void 
ICSetDigitalInput(void *data) {

    uint16_t tempId = (uint16_t)data;

    switch (tempId) {
        case 0: {
            /* IC1 */           
            TRISAbits.TRISA4 = 1; /* Set Digital Input, line will be pulled HIGH */
            break;
        }
        case 1: {
            /* IC2 */
            TRISAbits.TRISA3 = 1; /* Set Digital Input, line will be pulled HIGH */
            break;
        }
        case 2: {
            /* IC3 */
            TRISBbits.TRISB4 = 1; /* Set Digital Input, line will be pulled HIGH */
            break;
        }
        case 3: {
            /* IC4 */
            TRISAbits.TRISA8 = 1; /* Set Digital Input, line will be pulled HIGH */
            break;
        }
    }    
}

static void
setFanOff(uint16_t pwmId) {
    
//    if (!cfg.fan[pwmId].enabled) return;    
    
    // In the case of a 4 PIN fan we want to stop the fan completely
    // This is down by pulling the line down and causing the FET to 
    // remove power.
    
    // In the case of a 3 PIN fan the PWM signal is applied to the 
    // FET controlling the power and regulating the fan speed.
    
    // Currently we assume 4 pin FAN and override the power to 
    // always OFF

// TODO
//    if (fan[id].Use3Pin) {
//
//       switch (id) {
//           case 0:
//               PWM_OverrideHighDisable(3);
//               break;
//           case 1:
//               PWM_OverrideHighDisable(1);
//               break;
//           case 2:
//               PWM_OverrideHighDisable(2);
//               break;
//       }
//
//   } else {    
    
        switch (pwmId) {
            case 0:
                
                PWM_OverrideHighEnable(3);
                PWM_OverrideDataHighSet(3, 0);
                break;
            case 1:
                PWM_OverrideHighEnable(1);
                PWM_OverrideDataHighSet(1, 0);
                break;
            case 2:

                PWM_OverrideHighEnable(2);
                PWM_OverrideDataHighSet(2, 0);
                break;
        }
//    }
}
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
int 
main(void)
{            
    // Hardware Initialisation for dsPIC
    // MCU using 20MHz crystal, configured with 140MHz FOSC ( 70 MIPS )
    //
    // 4 Input Capture devices for interfacing with temp sensors supporting DHT11 and DHT22
    // 3 2-Channel PWM devices running at 25KHz for controlling 4pin PWN fans, 
    //   also support for 3pin and 2pin fans using PWM on power pin if required
    // 1 UART for communication, loggin with a host, configured at 9600 8N1 
    // 12 GPIOs - 2 dedicated to rotary encoder ( GPIO4, GPIO5 )
    //            1 dedicated to a button ( GPIO3 )
    //            3 Inputs set to interrupt on change reading TACH from fans to calculate RPM
    //            3 Output to FETs controlling FAN 12V input in the case of 3pin and 2pin fans
    //              and for power off control of 4pin fans
    //            3 GPIOS GPIO0, GPIO1, GPIO2 used to signal alarms for programs with failed fans, sensors
    // 3 Timers - TMR1 used as system timer used to monitor 10ms tick for scheduling
    //            TMR3 used by PWM hardware
    //            TMR4 used as high frequency timer with 7.3us tick
       
    CONFIGASSERT();


    // initialize the device
    SYSTEM_Initialize();

    // Get stored config data from flash or generate default
    configRead(&cfg);
        
    
    // Set GPIO0, GPIO1 and GPIO2 to digital outputs to be used
    // as alarms to signal when fans are not rotating
    
    GPIOSetType(0, GPIODigital);
    GPIOSetDirection(0, GPIOOutput);
    GPIOSetValue(0, 0);

    GPIOSetType(1, GPIODigital);
    GPIOSetDirection(1, GPIOOutput);
    GPIOSetValue(1, 0);

    GPIOSetType(2, GPIODigital);
    GPIOSetDirection(2, GPIOOutput);
    GPIOSetValue(2, 0);
        
    // Start with ALL fans off    
    setFanOff(0);
    setFanOff(1);
    setFanOff(2);

    // Video bringup    
    videoBufferInit(LCDROWS, LCDCOLS, videoBuffer, videoSetCursor, videoWriteChar, videoBusy, (void *)0);
    videoBufferClear();
        
    // Start bringing up the LCD    
    lcdInit(LCDROWS, LCDCOLS, LCDRWSet, LCDRSSet, LCDWriteDB, LCDReadDB, LCDESet, (void *)0);
        
    // Setup HAL for temp sensor capture hardware
    if (cfg.sensor[0].enabled) {
        dhtInit(0, cfg.sensor[0].type, ICInit, ICCaptureDataRead, ICStop, ICSetDigitalOuputLow, ICSetDigitalInput, (void *)TEMPID0);         
    }
    
    if (cfg.sensor[1].enabled) {
        dhtInit(1, cfg.sensor[1].type, ICInit, ICCaptureDataRead, ICStop, ICSetDigitalOuputLow, ICSetDigitalInput, (void *)TEMPID1); 
    }
    
    if (cfg.sensor[2].enabled) {
        dhtInit(2, cfg.sensor[2].type, ICInit, ICCaptureDataRead, ICStop, ICSetDigitalOuputLow, ICSetDigitalInput, (void *)TEMPID2); 
    }
    
    if (cfg.sensor[3].enabled) {
        dhtInit(3, cfg.sensor[3].type, ICInit, ICCaptureDataRead, ICStop, ICSetDigitalOuputLow, ICSetDigitalInput, (void *)TEMPID3); 
    }    
        
    // Startup all tasks with the exception of those that are delayed, they
    // are scheduled separately
    schedulerProcessAdd(&readTemperatureDelayProcess);
    schedulerProcessAdd(&monitorAllTempsProcess);
    schedulerProcessAdd(&userInterfaceProcess);
    schedulerProcessAdd(&buttonDebounceProcess);
    schedulerProcessAdd(&buttonPollProcess);
    schedulerProcessAdd(&encoderPollProcess);
    schedulerProcessAdd(&updateLCDInitProcess);                
    schedulerProcessAdd(&tachReadProcess);
    schedulerProcessAdd(&logDataProcess);
    schedulerProcessAdd(&monitorAlarmProcess);
#ifdef BLINK7BIT
    schedulerProcessAdd(&videoBlinkProcess);
#endif    
            
    // Encoder available to GPIO4 and GPIO5, set initial value, limits and step
    
#define ENCODERMIN   0    
#define ENCODERMAX   0
#define ENCODERVALUE 0
#define ENCODERSTEP  1
    
    encoderInit(ENCODERID, ENCODERGPIOB, ENCODERGPIOA, encoderCallback, (void *)ENCODERID, ENCODER_HALFSTEP);
    encoderSet(ENCODERID, ENCODERMIN, ENCODERMAX, ENCODERVALUE, ENCODERSTEP);
    encoderEnable(ENCODERID);

    // Button on GPIO3 ( encoder pushbutton )
    buttonEnable(BUTTONGPIOID, buttonCallback, (void *)0, 0);

    
    // Init a PID controller per TempSensor/FanPWM pair
    // NOTE - TempSensor3 has no associated FanPWM
        
    if (cfg.program[0].enabled) {        
        pidInit(0, cfg.program[0].targetTemp, cfg.program[0].P, cfg.program[0].I, pidGetInputValue, pidSetOutputValue, cfg.fan[0].minDuty, cfg.fan[0].maxDuty, ICInit, (void *)TEMPID0);
    }

    if (cfg.program[1].enabled) {
        pidInit(1, cfg.program[1].targetTemp, cfg.program[1].P, cfg.program[1].I, pidGetInputValue, pidSetOutputValue, cfg.fan[1].minDuty, cfg.fan[1].maxDuty, ICInit, (void *)TEMPID1);        
    }

    if (cfg.program[2].enabled) {
        pidInit(2, cfg.program[2].targetTemp, cfg.program[2].P, cfg.program[2].I, pidGetInputValue, pidSetOutputValue, cfg.fan[2].minDuty, cfg.fan[2].maxDuty, ICInit, (void *)TEMPID2);        
    }
    
    menuInit(menuEncoderSet, (void *)0, videoBlinkDelay, (void *)&videoBlinkProcess);

    while (1) {
        
        schedulerRun();
    }
    
    return 1; 
}
/**
 End of File
*/

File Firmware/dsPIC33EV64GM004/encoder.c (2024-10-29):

/* 
 *  Copyright (c) 2023 Angelo Masci
 * 
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
 */

/*  Statemachine ported from python version found with MIT license
 *  see: https://github.com/miketeachman/micropython-rotary 
 */

#include <stdint.h>

#include "GPIO.h"
#include "encoder.h"

struct encoder_s {

    uint16_t spare:13;
	uint16_t enabled:1;
    uint16_t halfStep:1;
    uint16_t changed:1;
    
    uint8_t gpioIdA;
    uint8_t gpioIdB;
    
	uint16_t min;
	uint16_t max;
	uint16_t value;
    uint16_t step;	
	uint16_t state;
    
    void (* func)(uint16_t id, uint16_t value, void *data);
    void *data;
};

static struct encoder_s encoders[MAXENCODERS];

// Encoder direction
#define DIR_CW    0x10 /* Clockwise step */
#define DIR_CCW   0x20 /* Counter-clockwise step */

// Rotary Encoder States
#define R_START   0x0
#define R_CW_1    0x1
#define R_CW_2    0x2
#define R_CW_3    0x3
#define R_CCW_1   0x4
#define R_CCW_2   0x5
#define R_CCW_3   0x6
#define R_ILLEGAL 0x7

static uint8_t stateTable[8][4] = {

    // |------------- NEXT STATE -------------|            |CURRENT STATE|
    // CLK/DT    CLK/DT     CLK/DT    CLK/DT
    //   00        01         10        11
    {R_START, R_CCW_1, R_CW_1,  R_START},             // R_START
    {R_CW_2,  R_START, R_CW_1,  R_START},             // R_CW_1
    {R_CW_2,  R_CW_3,  R_CW_1,  R_START},             // R_CW_2
    {R_CW_2,  R_CW_3,  R_START, R_START | DIR_CW},    // R_CW_3
    {R_CCW_2, R_CCW_1, R_START, R_START},             // R_CCW_1
    {R_CCW_2, R_CCW_1, R_CCW_3, R_START},             // R_CCW_2
    {R_CCW_2, R_START, R_CCW_3, R_START | DIR_CCW},   // R_CCW_3
    {R_START, R_START, R_START, R_START},             // R_ILLEGAL

};

static uint8_t stateTableHalfStep[8][4] = {
    {R_CW_3,            R_CW_2,  R_CW_1,  R_START},
    {R_CW_3 | DIR_CCW,  R_START, R_CW_1,  R_START},
    {R_CW_3 | DIR_CW,   R_CW_2,  R_START, R_START},
    {R_CW_3,            R_CCW_2, R_CCW_1, R_START},
    {R_CW_3,            R_CW_2,  R_CCW_1, R_START | DIR_CW},
    {R_CW_3,            R_CCW_2, R_CW_3,  R_START | DIR_CCW},
    {R_START,           R_START, R_START, R_START},
    {R_START,           R_START, R_START, R_START},

};

#define STATE_MASK 0x07
#define DIR_MASK   0x30


void 
encoderUpdate(void) {

	struct encoder_s *encoder = encoders;
	uint16_t id;

	for (id = 0; id < MAXENCODERS; id++) {

		if (encoder->enabled) {
		
            uint8_t  gpioIdA = encoder->gpioIdA;
            uint8_t  gpioIdB = encoder->gpioIdB;            
            uint16_t pins    = (GPIOGetValue(gpioIdA) << 1) | GPIOGetValue(gpioIdB);

            // Determine next state
            if (encoder->halfStep) {
                encoder->state = stateTableHalfStep[encoder->state & STATE_MASK][pins];
            } else {
                encoder->state = stateTable[encoder->state & STATE_MASK][pins];
            }
                       
            switch (encoder->state & DIR_MASK) {
                case DIR_CW: {
                   
                    encoder->value += encoder->step;
                    if (encoder->value > encoder->max) {
                        encoder->value = encoder->max;
                    }
                    
                    encoder->changed = 1;
                    break;
                }
                case DIR_CCW: {
                    
                    encoder->value -= encoder->step;
                    if (encoder->value < encoder->min) {
                        encoder->value = encoder->min;
                    }
                    
                    encoder->changed = 1;
                    break;
                }
            }
		}
            
        encoder++;		
    }
}

void
encoderUpdateChanged(void) {

    struct encoder_s *encoder = encoders;
	uint16_t id;

	for (id = 0; id < MAXENCODERS; id++) {
		if (encoder->enabled) {
            if (encoder->changed) {
                encoder->func(id, encoder->value, encoder->data);
                encoder->changed = 0;
            }
        }

        encoder++;		
    }    
}


void 
encoderDisable(uint16_t id) {

	struct encoder_s *encoder = &encoders[id];    
    uint8_t gpioIdA = encoder->gpioIdA;
    uint8_t gpioIdB = encoder->gpioIdB;
    
    GPIODisablePullDown(gpioIdA);
    GPIODisablePullUp(gpioIdA);

    GPIODisablePullDown(gpioIdB);
    GPIODisablePullUp(gpioIdB);
        
	encoder->enabled = 0;
}

void
encoderInit(uint16_t id, 
            uint8_t gpioIdA,
            uint8_t gpioIdB,
            void (* func)(uint16_t id, uint16_t value, void *data),
            void *data, 
            uint16_t flags) {
            
	struct encoder_s *encoder = &encoders[id];
        
    encoder->gpioIdA = gpioIdA;
    encoder->gpioIdB = gpioIdB;
    
    GPIOSetType(gpioIdA, GPIODigital);
    GPIOSetDirection(gpioIdA, GPIOInput);
    
    if ((flags & ENCODER_PULLUP) == ENCODER_PULLUP) {
        GPIOEnablePullUp(gpioIdA);
    }

    if ((flags & ENCODER_PULLDOWN) == ENCODER_PULLDOWN) {    
        GPIOEnablePullDown(gpioIdA);
    }
    
    GPIOSetType(gpioIdB, GPIODigital);
    GPIOSetDirection(gpioIdB, GPIOInput);

    if ((flags & ENCODER_PULLUP) == ENCODER_PULLUP) {
        GPIOEnablePullUp(gpioIdB);
    }

    if ((flags & ENCODER_PULLDOWN) == ENCODER_PULLDOWN) { 
        GPIOEnablePullDown(gpioIdB);
    }

    encoder->func     = func;
    encoder->data     = data;
    encoder->state    = 0;
	encoder->enabled  = 0;
    encoder->halfStep = (flags & ENCODER_HALFSTEP);    
}        



void 
encoderEnable(uint16_t id) {

	encoders[id].enabled = 1;
}

uint16_t
encoderGetEnabled(uint16_t id) {
    
    return encoders[id].enabled;
}

uint16_t 
encoderGetValue(uint16_t id) {
    
    return encoders[id].value;
}

void 
encoderSetValue(uint16_t id, uint16_t value) {
    
    encoders[id].value = value;
}

void 
encoderSet(uint16_t id,
           uint16_t min, 
           uint16_t max, 
           uint16_t value, 
		   uint16_t step) {
				
	struct encoder_s *encoder = &encoders[id];

 	encoder->min      = min;
	encoder->max      = max;
	encoder->value    = value;
	encoder->step     = step;
}

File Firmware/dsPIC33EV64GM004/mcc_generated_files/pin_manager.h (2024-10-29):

/**
  PIN MANAGER Generated Driver File

  @Company:
    Microchip Technology Inc.

  @File Name:
    pin_manager.h

  @Summary:
    This is the generated manager file for the PIC24 / dsPIC33 / PIC32MM MCUs device.  This manager
    configures the pins direction, initial state, analog setting.
    The peripheral pin select, PPS, configuration is also handled by this manager.

  @Description:
    This source file provides implementations for PIN MANAGER.
    Generation Information :
        Product Revision  :  PIC24 / dsPIC33 / PIC32MM MCUs - 1.171.4
        Device            :  dsPIC33EV64GM004
    The generated drivers are tested against the following:
        Compiler          :  XC16 v2.10
        MPLAB 	          :  MPLAB X v6.05
*/

/*
    (c) 2020 Microchip Technology Inc. and its subsidiaries. You may use this
    software and any derivatives exclusively with Microchip products.

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
    IN NO EVENT WILL MICROCHIP BE LIABLE FOR ANY INDIRECT, SPECIAL, PUNITIVE,
    INCIDENTAL OR CONSEQUENTIAL LOSS, DAMAGE, COST OR EXPENSE OF ANY KIND
    WHATSOEVER RELATED TO THE SOFTWARE, HOWEVER CAUSED, EVEN IF MICROCHIP HAS
    BEEN ADVISED OF THE POSSIBILITY OR THE DAMAGES ARE FORESEEABLE. TO THE
    FULLEST EXTENT ALLOWED BY LAW, MICROCHIP'S TOTAL LIABILITY ON ALL CLAIMS IN
    ANY WAY RELATED TO THIS SOFTWARE WILL NOT EXCEED THE AMOUNT OF FEES, IF ANY,
    THAT YOU HAVE PAID DIRECTLY TO MICROCHIP FOR THIS SOFTWARE.

    MICROCHIP PROVIDES THIS SOFTWARE CONDITIONALLY UPON YOUR ACCEPTANCE OF THESE
    TERMS.
*/

#ifndef _PIN_MANAGER_H
#define _PIN_MANAGER_H
/**
    Section: Includes
*/
#include <xc.h>

/**
    Section: Device Pin Macros
*/
/**
  @Summary
    Sets the GPIO pin, RA0, high using LATA0.

  @Description
    Sets the GPIO pin, RA0, high using LATA0.

  @Preconditions
    The RA0 must be set to an output.

  @Returns
    None.

  @Param
    None.

  @Example
    <code>
    // Set RA0 high (1)
    GPIO0_SetHigh();
    </code>

*/
#define GPIO0_SetHigh()          (_LATA0 = 1)
/**
  @Summary
    Sets the GPIO pin, RA0, low using LATA0.

  @Description
    Sets the GPIO pin, RA0, low using LATA0.

  @Preconditions
    The RA0 must be set to an output.

  @Returns
    None.

  @Param
    None.

  @Example
    <code>
    // Set RA0 low (0)
    GPIO0_SetLow();
    </code>

*/
#define GPIO0_SetLow()           (_LATA0 = 0)
/**
  @Summary
    Toggles the GPIO pin, RA0, using LATA0.

  @Description
    Toggles the GPIO pin, RA0, using LATA0.

  @Preconditions
    The RA0 must be set to an output.

  @Returns
    None.

  @Param
    None.

  @Example
    <code>
    // Toggle RA0
    GPIO0_Toggle();
    </code>

*/
#define GPIO0_Toggle()           (_LATA0 ^= 1)
/**
  @Summary
    Reads the value of the GPIO pin, RA0.

  @Description
    Reads the value of the GPIO pin, RA0.

  @Preconditions
    None.

  @Returns
    None.

  @Param
    None.

  @Example
    <code>
    uint16_t portValue;

    // Read RA0
    postValue = GPIO0_GetValue();
    </code>

*/
#define GPIO0_GetValue()         _RA0
/**
  @Summary
    Configures the GPIO pin, RA0, as an input.

  @Description
    Configures the GPIO pin, RA0, as an input.

  @Preconditions
    None.

  @Returns
    None.

  @Param
    None.

  @Example
    <code>
    // Sets the RA0 as an input
    GPIO0_SetDigitalInput();
    </code>

*/
#define GPIO0_SetDigitalInput()  (_TRISA0 = 1)
/**
  @Summary
    Configures the GPIO pin, RA0, as an output.

  @Description
    Configures the GPIO pin, RA0, as an output.

  @Preconditions
    None.

  @Returns
    None.

  @Param
    None.

  @Example
    <code>
    // Sets the RA0 as an output
    GPIO0_SetDigitalOutput();
    </code>

*/
#define GPIO0_SetDigitalOutput() (_TRISA0 = 0)
/**
  @Summary
    Sets the GPIO pin, RA1, high using LATA1.

  @Description
    Sets the GPIO pin, RA1, high using LATA1.

  @Preconditions
    The RA1 must be set to an output.

  @Returns
    None.

  @Param
    None.

  @Example
    <code>
    // Set RA1 high (1)
    GPIO1_SetHigh();
    </code>
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

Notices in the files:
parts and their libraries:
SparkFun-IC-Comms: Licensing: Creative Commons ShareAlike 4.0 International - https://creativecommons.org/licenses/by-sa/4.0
